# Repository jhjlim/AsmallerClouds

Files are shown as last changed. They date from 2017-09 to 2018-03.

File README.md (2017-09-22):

# AsmallerClouds
Schematic/board files for an 8HP version of Clouds

This Eagle project uses the original mutable instruments design files. It simply repositions all components to fit in an 8HP module.
I did this layout as a side project because I love the clouds module and wanted more in my system without sacrificing other space! The only component changes are the crystals to a smaller package, 3mm red/green LEDs and a different illuminated push button. The RESET(SW5) and SYSBOOT(SW4) tactile switches were also dropped and replaced with accesible pads that can be shorted.

Original CAD file, PCB & Schematic and original design elements provided by Mutable Instruments under creative commons CC-BY-SA-3.0 license.

Design contributions are provided by Jason H. J. Lim under Creative Commons CC-BY-SA-3.0 license.

Support of DIY builds is not provided by myself nor Mutable Instruments nor the Mutable Instruments forums, please respect their wishes to not want to answer any questions regarding DIY builds and leave them to continue doing what they do best.

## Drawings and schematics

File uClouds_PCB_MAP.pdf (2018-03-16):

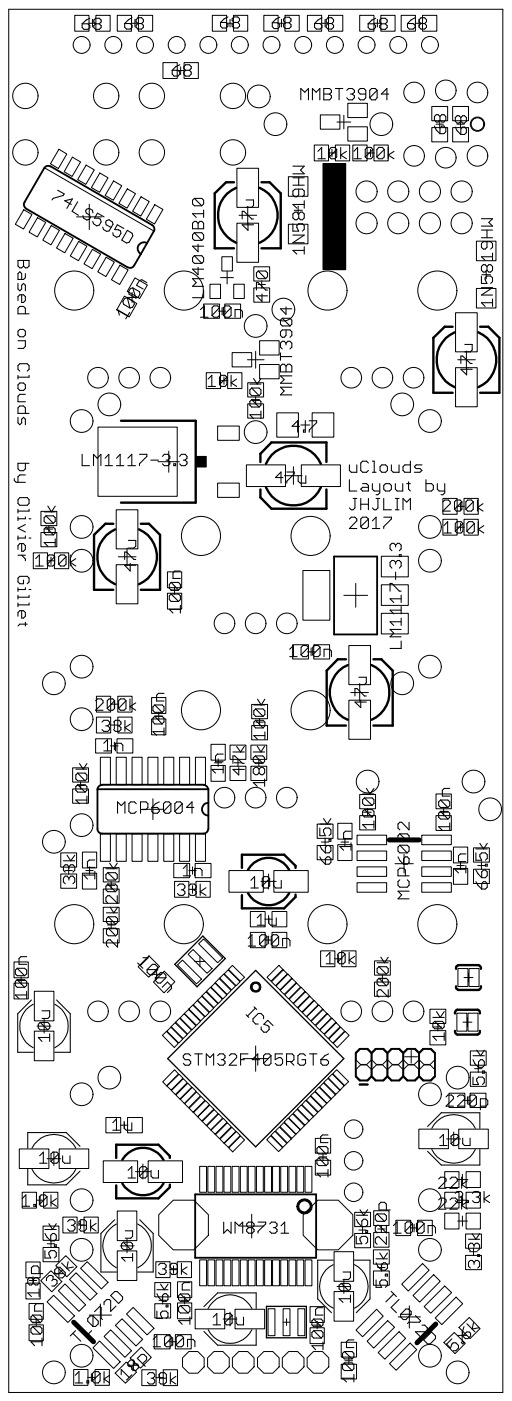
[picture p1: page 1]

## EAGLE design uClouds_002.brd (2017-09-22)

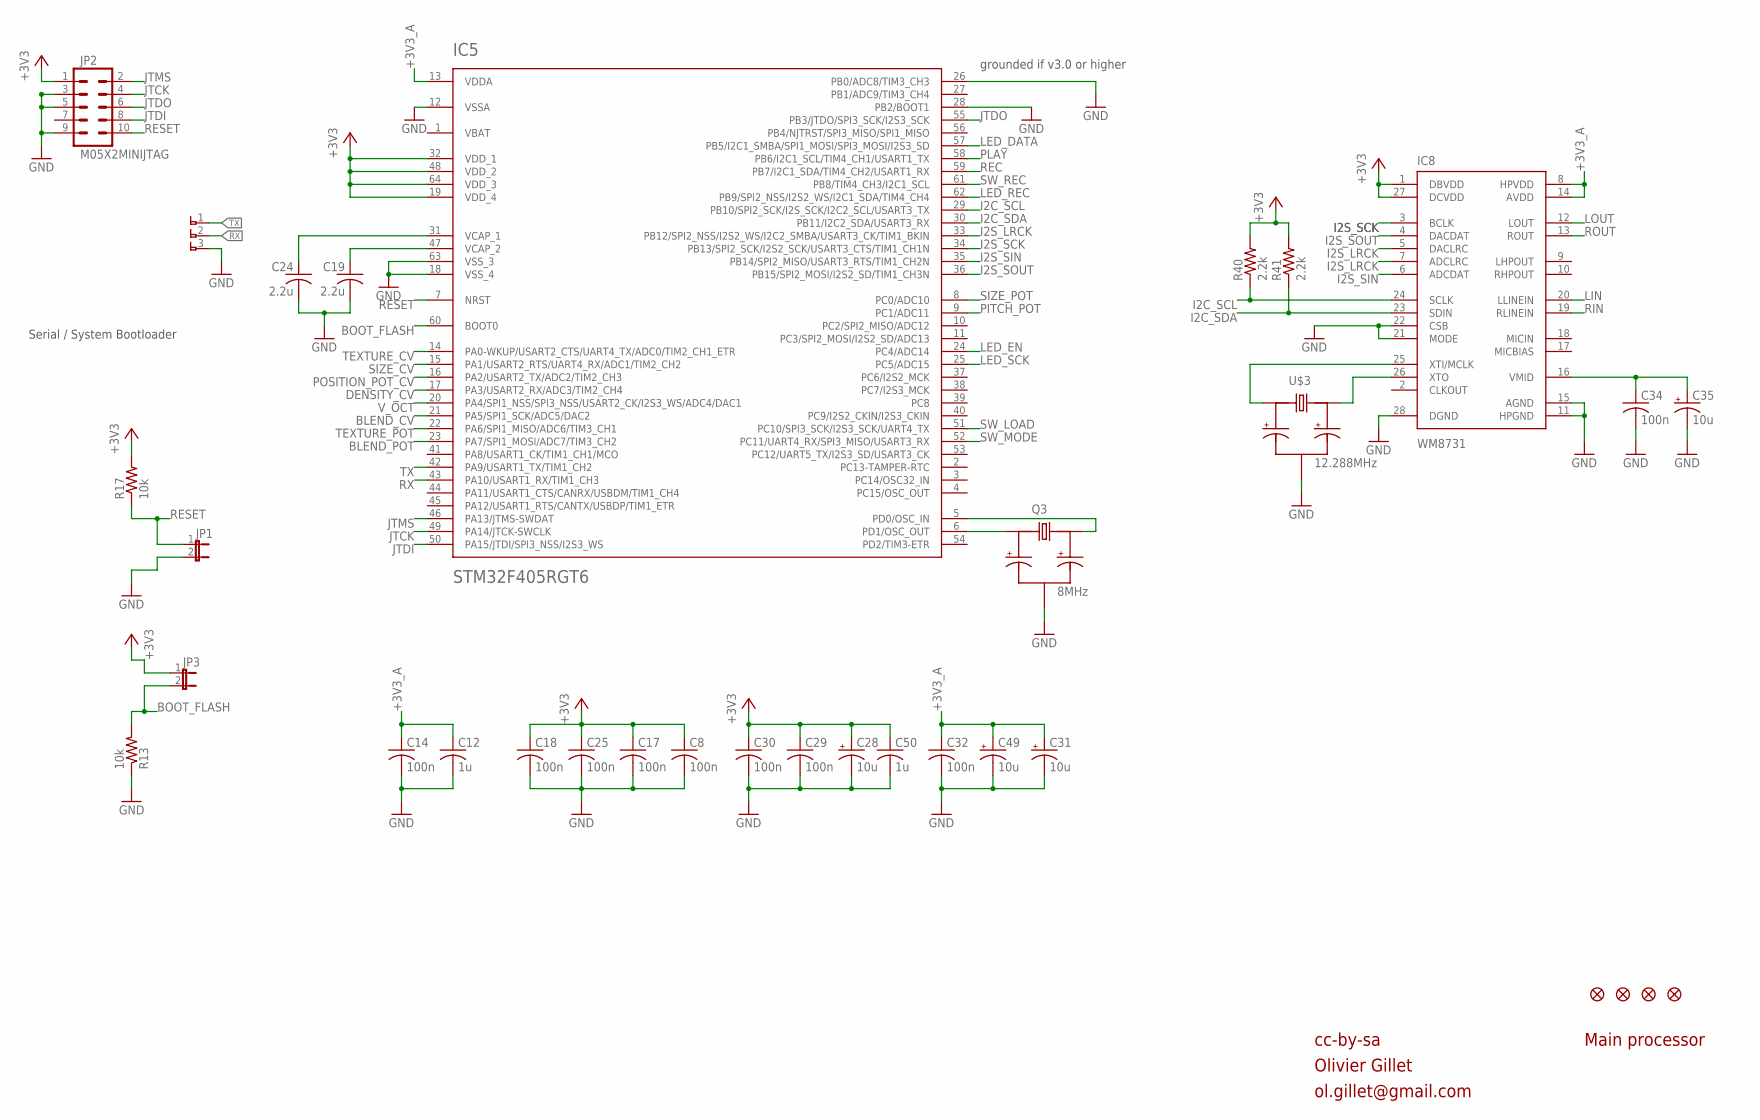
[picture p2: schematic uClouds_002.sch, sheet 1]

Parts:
C8, C32, C34: 100n; C0603
C12, C50: 1u; C0603K
C14, C17, C18, C25, C29, C30: 100n; C0603K
C19, C24: 2.2u; C0805K
C28: 10u; 153CLV-0405
C31, C35: 10u; PANASONIC_B
C49: 10u; PANASONIC_A
F1, F2, F3, F4: FIDUCIAL1X2; FIDUCIAL-1X2
IC5: STM32F405RGT6; TQFP-10X10-64
IC8: WM8731; SSOP28
JP1, JP3: JUMPER-2SMD-NO; SJ_2S-NO
JP2: M05X2MINIJTAG; 2X5-1.27
Q3: 8MHz; CRYSTAL_SMALLER
R13, R17: 10k; R0603
R40, R41: 2.2k; R0603
U$3: 12.288MHz; CRYSTAL_SMALLER
U$4: 1X3_SMALL

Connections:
+3V3: C8.1, C17.1, C18.1, C25.1, C28.+, C29.1, C30.1, C50.1, IC5.19 (VDD_4), IC5.32 (VDD_1), IC5.48 (VDD_2), IC5.64 (VDD_3), IC8.1 (DBVDD), IC8.27 (DCVDD), JP2.1, JP3.1, R17.2, R40.2, R41.2; also elsewhere on the board
+3V3_A: C12.1, C14.1, C31.+, C32.1, C49.+, IC5.13 (VDDA), IC8.8 (HPVDD), IC8.14 (AVDD); also elsewhere on the board
BLEND_CV: IC5.21 (PA5/SPI1_SCK/ADC5/DAC2); also elsewhere on the board
BLEND_POT: IC5.23 (PA7/SPI1_MOSI/ADC7/TIM3_CH2); also elsewhere on the board
BOOT_FLASH: IC5.60 (BOOT0), JP3.2, R13.2
DENSITY_CV: IC5.17 (PA3/USART2_RX/ADC3/TIM2_CH4); also elsewhere on the board
GND: C8.2, C12.2, C14.2, C17.2, C18.2, C19.2, C24.2, C25.2, C28.-, C29.2, C30.2, C31.-, C32.2, C34.2, C35.-, C49.-, C50.2, IC5.12 (VSSA), IC5.18 (VSS_4), IC5.26 (PB0/ADC8/TIM3_CH3), IC5.28 (PB2/BOOT1), IC5.63 (VSS_3), IC8.11 (HPGND), IC8.15 (AGND), IC8.21 (MODE), IC8.22 (CSB), IC8.28 (DGND), JP1.2, JP2.3, JP2.5, JP2.9, Q3.GND, R13.1, U$3.GND, U$4.3; also elsewhere on the board
I2C_SCL: IC5.29 (PB10/SPI2_SCK/I2S_SCK/I2C2_SCL/USART3_TX), IC8.24 (SCLK), R40.1
I2C_SDA: IC5.30 (PB11/I2C2_SDA/USART3_RX), IC8.23 (SDIN), R41.1
I2S_LRCK: IC5.33 (PB12/SPI2_NSS/I2S2_WS/I2C2_SMBA/USART3_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), IC8.5 (DACLRC), IC8.7 (ADCLRC)
I2S_SCK: IC5.34 (PB13/SPI2_SCK/I2S2_SCK/USART3_CTS/TIM1_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), IC8.3 (BCLK)
I2S_SIN: IC5.35 (PB14/SPI2_MISO/USART3_RTS/TIM1_CH2N), IC8.6 (ADCDAT)
I2S_SOUT: IC5.36 (PB15/SPI2_MOSI/I2S2_SD/TIM1_CH3N), IC8.4 (DACDAT)
JTCK: IC5.49 (PA14/JTCK-SWCLK), JP2.4
JTDI: IC5.50 (PA15/JTDI/SPI3_NSS/I2S3_WS), JP2.8
JTDO: IC5.55 (PB3/JTDO/SPI3_SCK/I2S3_SCK), JP2.6
JTMS: IC5.46 (PA13/JTMS-SWDAT), JP2.2
LED_DATA: IC5.57 (PB5/I2C1_SMBA/SPI1_MOSI/SPI3_MOSI/I2S3_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); also elsewhere on the board
LED_EN: IC5.24 (PC4/ADC14); also elsewhere on the board
LED_REC: IC5.62 (PB9/SPI2_NSS/I2S2_WS/I2C1_SDA/TIM4_CH4); also elsewhere on the board
LED_SCK: IC5.25 (PC5/ADC15); also elsewhere on the board
LIN: IC8.20 (LLINEIN); also elsewhere on the board
LOUT: IC8.12 (LOUT); also elsewhere on the board
unnamed: IC5.6 (PD1/OSC_OUT), Q3.X1
unnamed: IC8.25 (XTI/MCLK), U$3.X1
unnamed: IC5.5 (PD0/OSC_IN), Q3.X2
unnamed: C19.1, IC5.47 (VCAP_2)
unnamed: C34.1, C35.+, IC8.16 (VMID)
unnamed: C24.1, IC5.31 (VCAP_1)
unnamed: IC8.26 (XTO), U$3.X2
PITCH_POT: IC5.9 (PC1/ADC11); also elsewhere on the board
PLAY: IC5.58 (PB6/I2C1_SCL/TIM4_CH1/USART1_TX); also elsewhere on the board
POSITION_POT_CV: IC5.16 (PA2/USART2_TX/ADC2/TIM2_CH3); also elsewhere on the board
REC: IC5.59 (PB7/I2C1_SDA/TIM4_CH2/USART1_RX); also elsewhere on the board
RESET: IC5.7 (NRST), JP1.1, JP2.10, R17.1
RIN: IC8.19 (RLINEIN); also elsewhere on the board
ROUT: IC8.13 (ROUT); also elsewhere on the board
RX: IC5.43 (PA10/USART1_RX/TIM1_CH3), U$4.2
SIZE_CV: IC5.15 (PA1/USART2_RTS/UART4_RX/ADC1/TIM2_CH2); also elsewhere on the board
SIZE_POT: IC5.8 (PC0/ADC10); also elsewhere on the board
SW_LOAD: IC5.51 (PC10/SPI3_SCK/I2S3_SCK/UART4_TX); also elsewhere on the board
SW_MODE: IC5.52 (PC11/UART4_RX/SPI3_MISO/USART3_RX); also elsewhere on the board
SW_REC: IC5.61 (PB8/TIM4_CH3/I2C1_SCL); also elsewhere on the board
TEXTURE_CV: IC5.14 (PA0-WKUP/USART2_CTS/UART4_TX/ADC0/TIM2_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); also elsewhere on the board
TEXTURE_POT: IC5.22 (PA6/SPI1_MISO/ADC6/TIM3_CH1); also elsewhere on the board
TX: IC5.42 (PA9/USART1_TX/TIM1_CH2), U$4.1
VBAT: IC5.1 (VBAT)
V_OCT: IC5.20 (PA4/SPI1_NSS/SPI3_NSS/USART2_CK/I2S3_WS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); also elsewhere on the board

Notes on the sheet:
cc-by-sa
Olivier Gillet
ol.gillet@gmail.com
Main processor
Serial / System Bootloader
grounded if v3.0 or higher

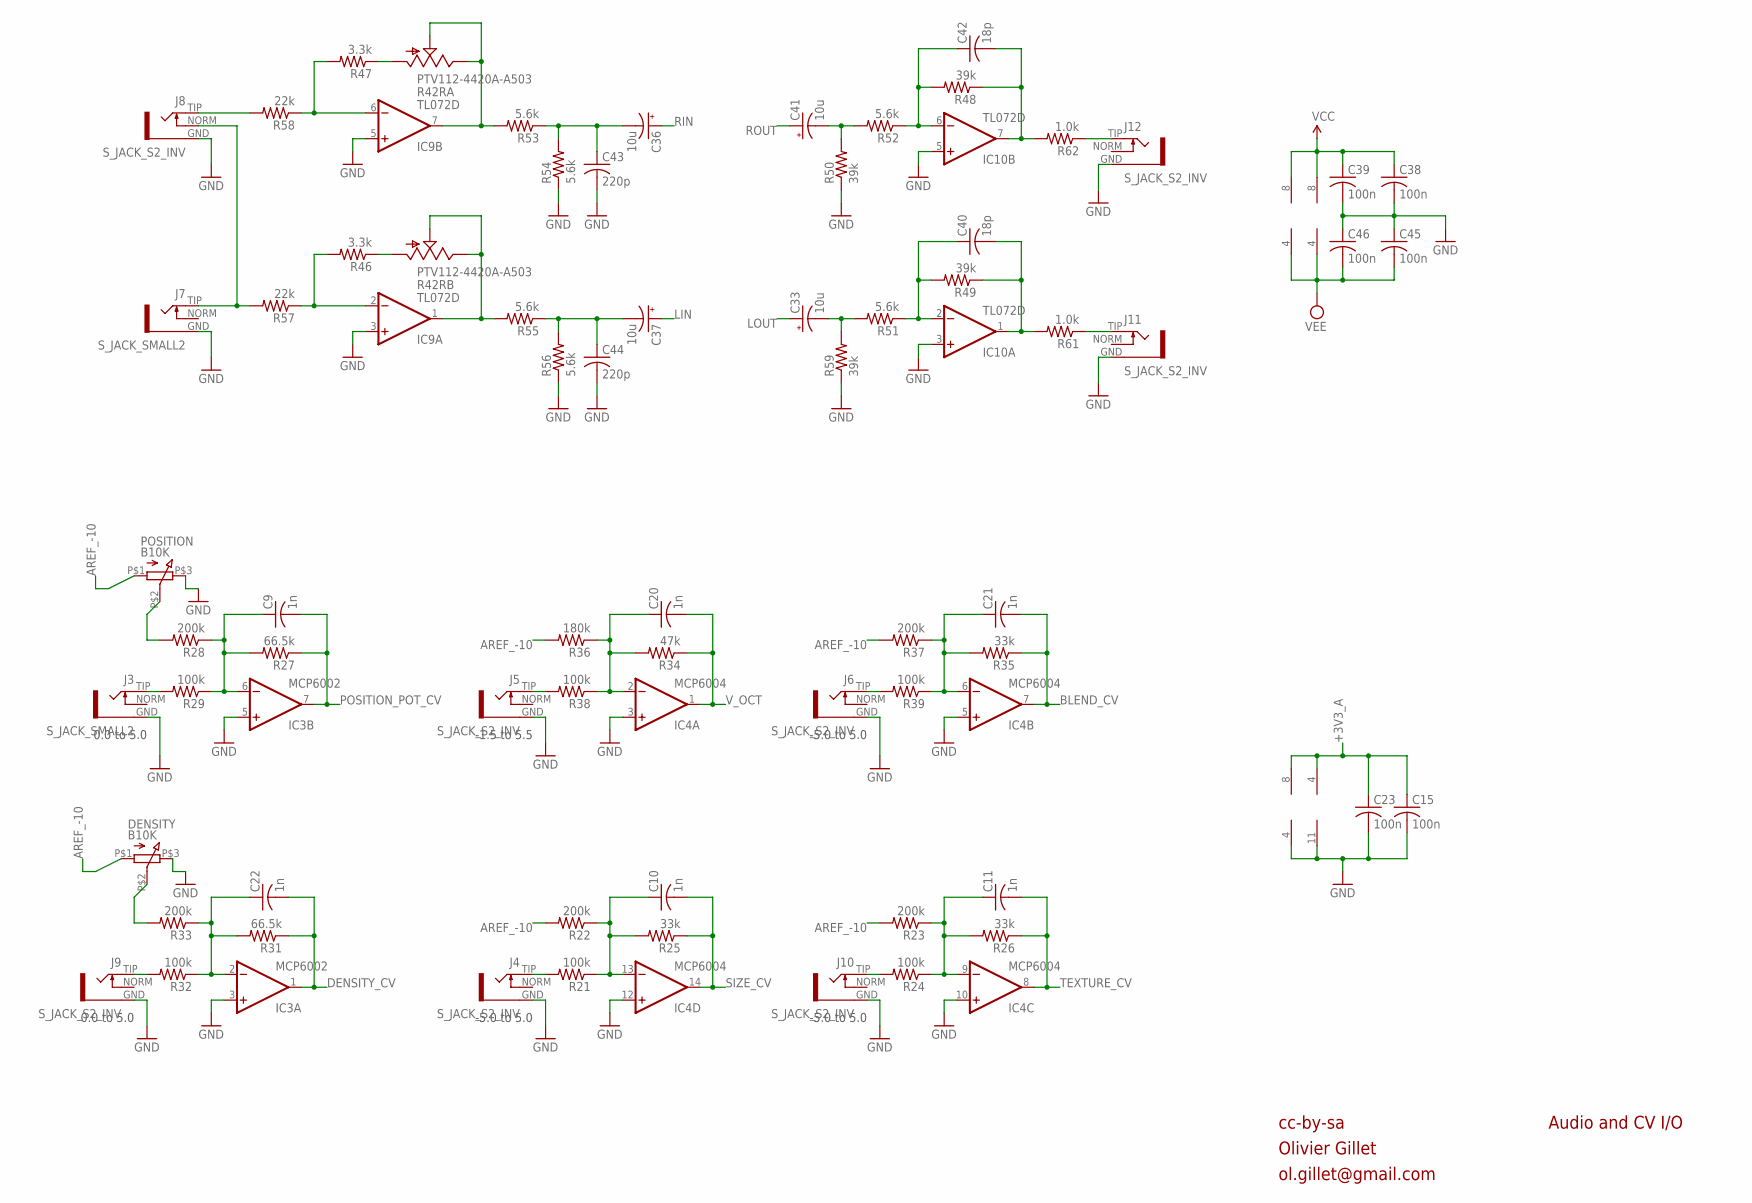
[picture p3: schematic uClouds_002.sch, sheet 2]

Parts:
C9, C10, C11, C20, C21, C22: 1n; C0603
C15, C39, C46: 100n; C0603K
C23, C38, C45: 100n; C0603
C33, C36, C37, C41: 10u; PANASONIC_B
C40, C42: 18p; C0603
C43: 220p; C0603K
C44: 220p; C0603
DENSITY: B10K; Q-POT2
IC3: MCP6002; SO08
IC4: MCP6004; SO14
IC9, IC10: TL072D; SO08
J3, J7: S_JACK_SMALL2
J4, J5, J6, J8, J9, J10, J11, J12: S_JACK_S2_INV
POSITION: B10K; Q-POT2
R21, R24, R29, R32, R38, R39: 100k; R0603
R22, R23, R28, R33, R37: 200k; R0603
R25, R26, R35: 33k; R0603
R27, R31: 66.5k; R0603
R34: 47k; R0603
R36: 180k; R0603
R42: PTV112-4420A-A503; BOURNS_PTV112
R46, R47: 3.3k; R0603
R48, R49, R50, R59: 39k; R0603
R51, R52, R53, R54, R55, R56: 5.6k; R0603
R57, R58: 22k; R0603
R61, R62: 1.0k; R0603

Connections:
+3V3_A: C15.1, C23.1, IC3.8 (V+), IC4.4 (V+); also elsewhere on the board
AREF_-10: DENSITY.P$1 (1), POSITION.P$1 (1), R22.2, R23.2, R36.2, R37.2; also elsewhere on the board
BLEND_CV: C21.2, IC4.7 (OUT), R35.1; also elsewhere on the board
DENSITY_CV: C22.2, IC3.1 (OUT), R31.1; also elsewhere on the board
GND: C15.2, C23.2, C38.2, C39.2, C43.2, C44.2, C45.1, C46.1, DENSITY.P$3 (3), IC3.3 (+IN), IC3.4 (V-), IC3.5 (+IN), IC4.3 (+IN), IC4.5 (+IN), IC4.10 (+IN), IC4.11 (V-), IC4.12 (+IN), IC9.3 (+IN), IC9.5 (+IN), IC10.3 (+IN), IC10.5 (+IN), J3.GND, J4.GND, J5.GND, J6.GND, J7.GND, J8.GND, J9.GND, J10.GND, J11.GND, J12.GND, POSITION.P$3 (3), R50.1, R54.1, R56.1, R59.1; also elsewhere on the board
LIN: C37.+; also elsewhere on the board
LOUT: C33.+; also elsewhere on the board
LOUT_JACK: J11.TIP, R61.1
unnamed: J4.TIP, R21.2
unnamed: C10.1, IC4.13 (-IN), R21.1, R22.1, R25.2
unnamed: J10.TIP, R24.2
unnamed: C11.1, IC4.9 (-IN), R23.1, R24.1, R26.2
unnamed: J6.TIP, R39.2
unnamed: J5.TIP, R38.2
unnamed: C20.1, IC4.2 (-IN), R34.2, R36.1, R38.1
unnamed: J9.TIP, R32.2
unnamed: C21.1, IC4.6 (-IN), R35.2, R37.1, R39.1
unnamed: C37.-, C44.1, R55.1, R56.2
unnamed: J8.TIP, R58.2
unnamed: J7.TIP, J8.NORM, R57.2
unnamed: C36.-, C43.1, R53.1, R54.2
unnamed: C41.-, R50.2, R52.2
unnamed: C22.1, IC3.2 (-IN), R31.2, R32.1, R33.1
unnamed: C42.1, IC10.6 (-IN), R48.2, R52.1
unnamed: DENSITY.P$2 (2), R33.2
unnamed: J3.TIP, R29.2
unnamed: C42.2, IC10.7 (OUT), R48.1, R62.2
unnamed: C9.1, IC3.6 (-IN), R27.2, R28.1, R29.1
unnamed: C33.-, R51.2, R59.2
unnamed: C40.1, IC10.2 (-IN), R49.2, R51.1
unnamed: C40.2, IC10.1 (OUT), R49.1, R61.2
unnamed: POSITION.P$2 (2), R28.2
unnamed: IC9.7 (OUT), R42.2P (S), R42.3P (E), R53.2
unnamed: IC9.1 (OUT), R42.2 (S), R42.3 (E), R55.2
unnamed: R42.1P (A), R47.1
unnamed: R42.1 (A), R46.1
unnamed: IC9.6 (-IN), R47.2, R58.1
unnamed: IC9.2 (-IN), R46.2, R57.1
POSITION_POT_CV: C9.2, IC3.7 (OUT), R27.1; also elsewhere on the board
RIN: C36.+; also elsewhere on the board
ROUT: C41.+; also elsewhere on the board
ROUT_JACK: J12.TIP, R62.1
SIZE_CV: C10.2, IC4.14 (OUT), R25.1; also elsewhere on the board
TEXTURE_CV: C11.2, IC4.8 (OUT), R26.1; also elsewhere on the board
VCC: C38.1, C39.1, IC9.8 (V+), IC10.8 (V+); also elsewhere on the board
VEE: C45.2, C46.2, IC9.4 (V-), IC10.4 (V-); also elsewhere on the board
V_OCT: C20.2, IC4.1 (OUT), R34.1; also elsewhere on the board

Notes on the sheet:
cc-by-sa
Olivier Gillet
ol.gillet@gmail.com
Audio and CV I/O
0.0 to 5.0
-1.5 to 5.5
-5.0 to 5.0

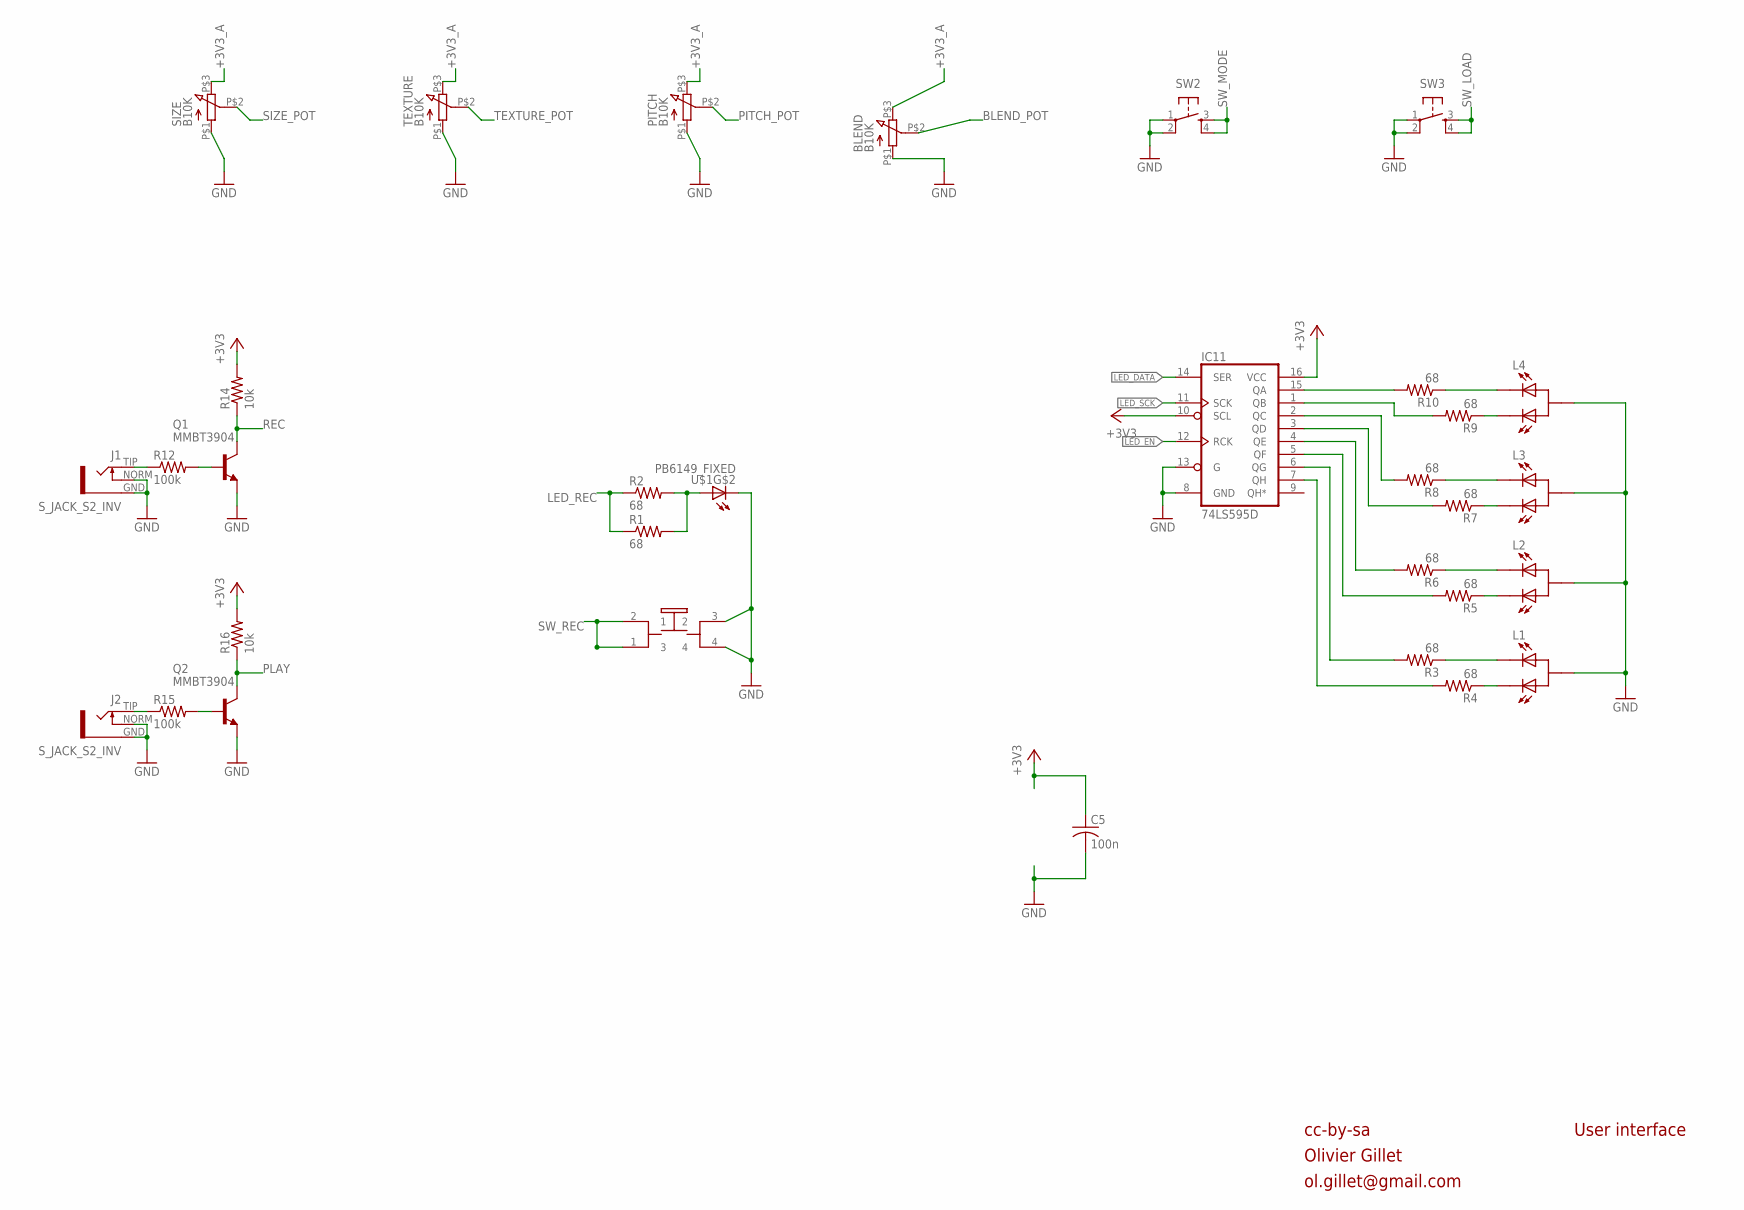
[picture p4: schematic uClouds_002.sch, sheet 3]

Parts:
BLEND: B10K; Q-POT2
C5: 100n; C0603
IC11: 74LS595D; SO16
J1, J2: S_JACK_S2_INV
L1, L2, L3, L4: LED_3MM_3PIN
PITCH: B10K; Q-POT2
Q1, Q2: MMBT3904; SOT23-BEC
R1, R2, R3, R4, R5, R6, R7, R8, R9, R10: 68; R0603
R12, R15: 100k; R0603
R14, R16: 10k; R0603
SIZE: B10K; Q-POT2
SW2, SW3: TAC_SWITCHPTH; TACTILE-PTH
TEXTURE: B10K; Q-POT2
U$1: PB6149_FIXED; PB6149L

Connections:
+3V3: C5.1, IC11.10 (SCL), IC11.16 (VCC), R14.2, R16.2; also elsewhere on the board
+3V3_A: BLEND.P$3 (3), PITCH.P$3 (3), SIZE.P$3 (3), TEXTURE.P$3 (3); also elsewhere on the board
BLEND_POT: BLEND.P$2 (2); also elsewhere on the board
GND: BLEND.P$1 (1), C5.2, IC11.8 (GND), IC11.13 (G), J1.GND, J1.NORM, J2.GND, J2.NORM, L1.A, L2.A, L3.A, L4.A, PITCH.P$1 (1), Q1.E, Q2.E, SIZE.P$1 (1), SW2.1, SW2.2, SW3.1, SW3.2, TEXTURE.P$1 (1), U$1.3 (2), U$1.4, U$1.K (C); also elsewhere on the board
LED_DATA: IC11.14 (SER); also elsewhere on the board
LED_EN: IC11.12 (RCK); also elsewhere on the board
LED_REC: R1.1, R2.1; also elsewhere on the board
LED_SCK: IC11.11 (SCK); also elsewhere on the board
unnamed: L4.C1, R9.1
unnamed: L4.C2, R10.1
unnamed: L3.C2, R8.1
unnamed: L3.C1, R7.1
unnamed: L2.C2, R6.1
unnamed: J2.TIP, R15.1
unnamed: Q2.B, R15.2
unnamed: R1.2, R2.2, U$1.A
unnamed: L2.C1, R5.1
unnamed: L1.C2, R3.1
unnamed: L1.C1, R4.1
unnamed: IC11.15 (QA), R10.2
unnamed: IC11.1 (QB), R9.2
unnamed: IC11.2 (QC), R8.2
unnamed: IC11.3 (QD), R7.2
unnamed: IC11.4 (QE), R6.2
unnamed: IC11.5 (QF), R5.2
unnamed: IC11.6 (QG), R3.2
unnamed: IC11.7 (QH), R4.2
unnamed: J1.TIP, R12.1
unnamed: Q1.B, R12.2
PITCH_POT: PITCH.P$2 (2); also elsewhere on the board
PLAY: Q2.C, R16.1; also elsewhere on the board
REC: Q1.C, R14.1; also elsewhere on the board
SIZE_POT: SIZE.P$2 (2); also elsewhere on the board
SW_LOAD: SW3.3, SW3.4; also elsewhere on the board
SW_MODE: SW2.3, SW2.4; also elsewhere on the board
SW_REC: U$1.1 (3), U$1.2 (1); also elsewhere on the board
TEXTURE_POT: TEXTURE.P$2 (2); also elsewhere on the board

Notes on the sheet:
cc-by-sa
Olivier Gillet
ol.gillet@gmail.com
User interface

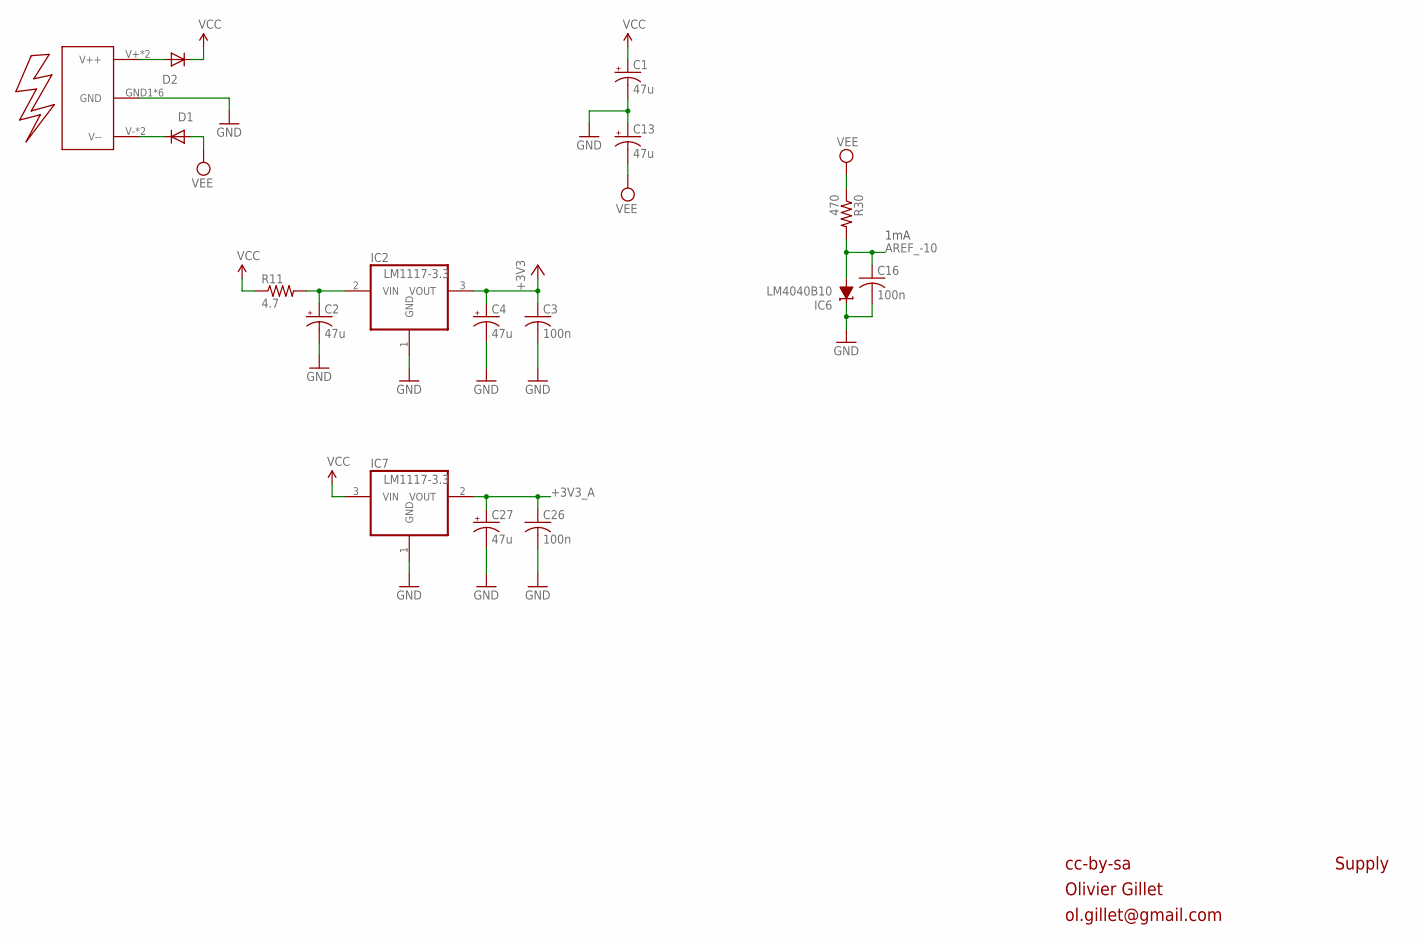
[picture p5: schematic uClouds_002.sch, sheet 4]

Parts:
C1, C2, C4, C13, C27: 47u; 153CLV-0505
C3, C16, C26: 100n; C0603
D1, D2: 1N5819HW; SOD123
IC2: LM1117-3.3; TO252
IC6: LM4040B10; DBZ_R-PDSO-G3
IC7: LM1117-3.3; SOT223
R11: 4.7; R1206
R30: 470; R0603
U$2: EURO_POWER2

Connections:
+3V3: C3.1, C4.+, IC2.3 (VOUT); also elsewhere on the board
+3V3_A: C26.1, C27.+, IC7.2 (VOUT); also elsewhere on the board
AREF_-10: C16.1, IC6.2 (A), R30.2; also elsewhere on the board
GND: C1.-, C2.-, C3.2, C4.-, C13.+, C16.2, C26.2, C27.-, IC2.1 (GND), IC6.1 (C), IC7.1 (GND), U$2.GND1 (GND), U$2.GND2 (GND), U$2.GND3 (GND), U$2.GND4 (GND), U$2.GND5 (GND), U$2.GND6 (GND); also elsewhere on the board
unnamed: C2.+, IC2.2 (VIN), R11.2
unnamed: D2.A, U$2.V+ (V++), U$2.V++
unnamed: D1.C, U$2.V- (V--), U$2.V--
VCC: C1.+, D2.C, IC7.3 (VIN), R11.1; also elsewhere on the board
VEE: C13.-, D1.A, R30.1; also elsewhere on the board

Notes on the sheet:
1mA
cc-by-sa
Olivier Gillet
ol.gillet@gmail.com
Supply

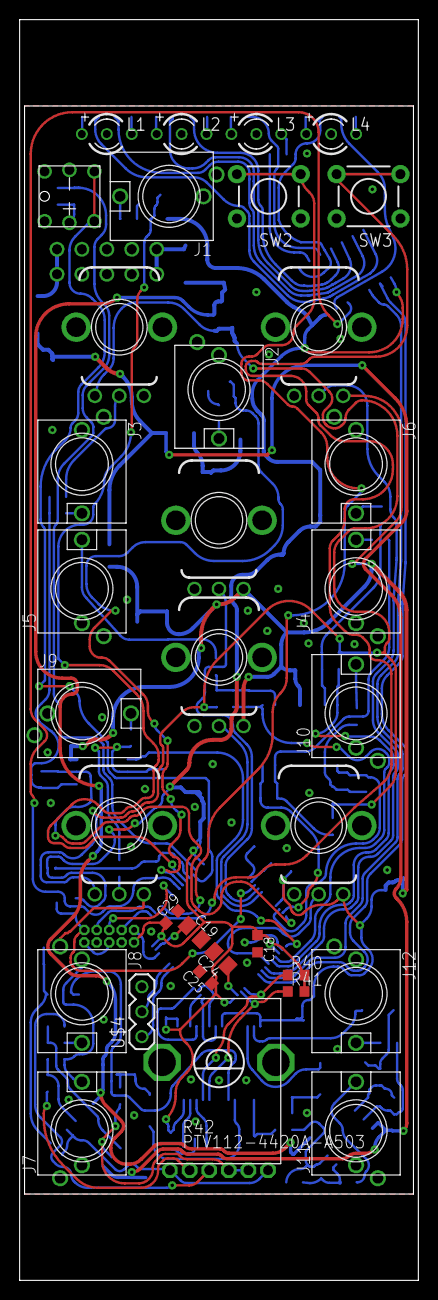
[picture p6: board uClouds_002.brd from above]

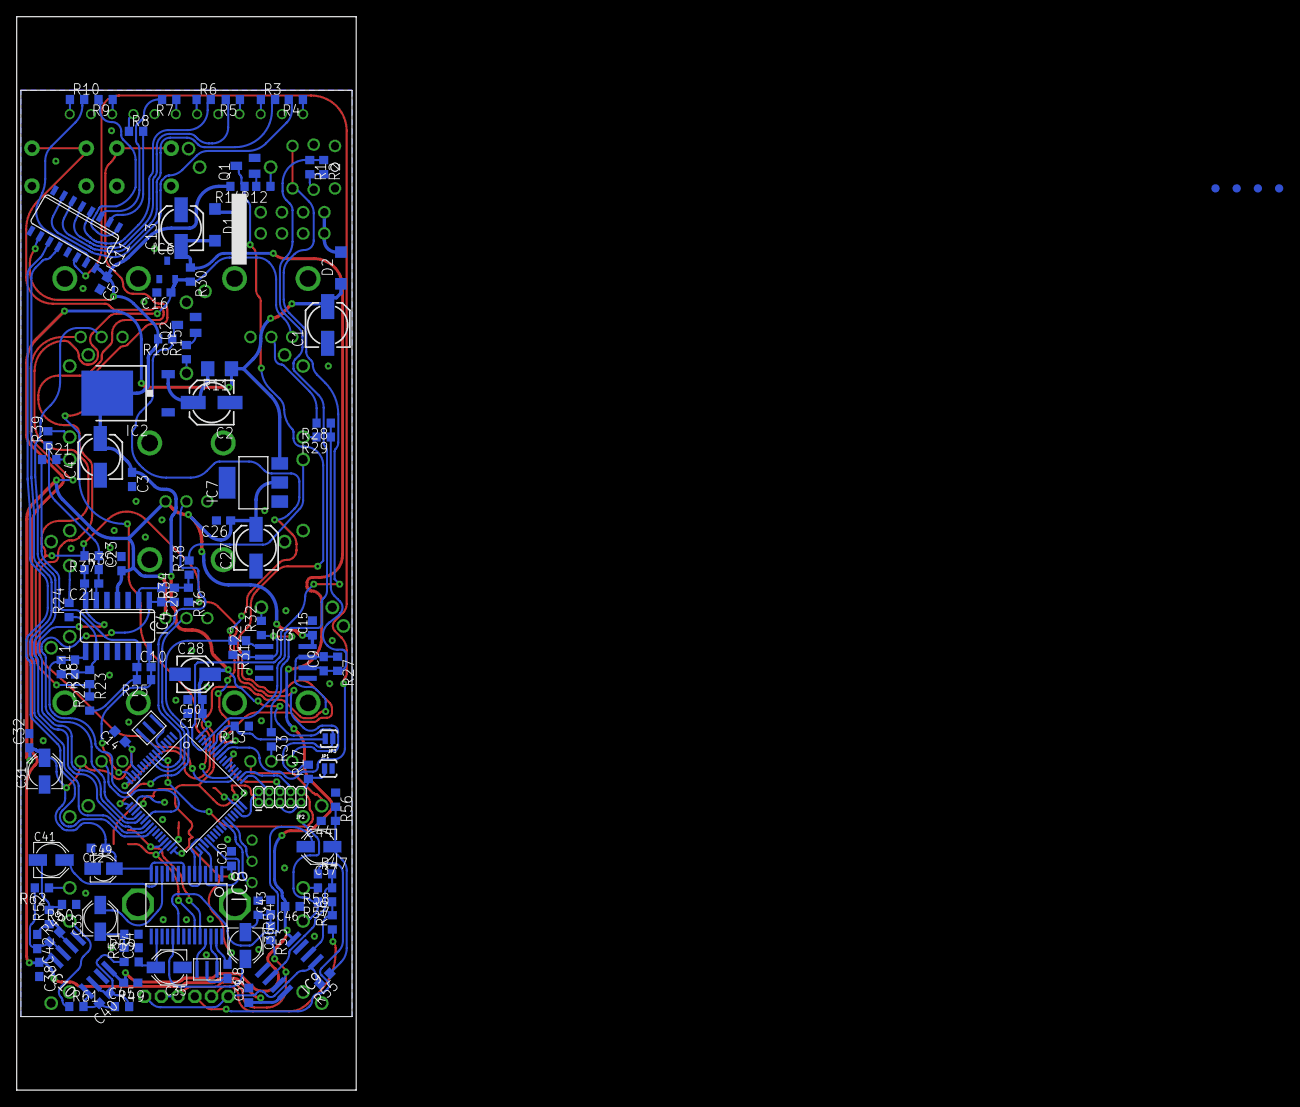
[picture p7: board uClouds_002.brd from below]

Board: 2 copper layers, 40.6 x 128.5 mm, 151 parts (116 on the bottom side), 106 nets.

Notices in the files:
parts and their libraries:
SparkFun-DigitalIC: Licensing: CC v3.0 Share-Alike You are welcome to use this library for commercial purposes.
